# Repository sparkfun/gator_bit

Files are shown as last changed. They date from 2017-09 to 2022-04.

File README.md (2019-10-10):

SparkFun gator:bit v2
========================================

SparkFun gator:bit v2

[*SparkFun gator:bit v2 (15162)*](https://www.sparkfun.com/products/15162)

The SparkFun gator:bit is an all-in-one prototyping platform for the micro:bit. Each pin is accessible by alligator clip, eliminating the need for breadboard or jumper wires.

Repository Contents
------------------
* **/Firmware** - Example code used with gator:bit. While they are compiled HEX codes, you can modify the example code once they are imported into MakeCode editor.
* **/Hardware** - Eagle design files (.brd, .sch)
* **/Production** - Production panel files (.brd)

Documentation
--------------
* **[Hookup Guide](https://learn.sparkfun.com/tutorials/sparkfun-gatorbit-v20-hookup-guide)** - Basic hookup guide for the gator:bit v2.

Versions
--------------
* **[v1](https://github.com/sparkfun/gator_bit/tree/v10)** - Version 1, Initial Release
* **[v2](https://github.com/sparkfun/gator_bit/)** - Version 2, Updated power handling, output pins now reach a proper voltage.

License Information
-------------------

This product is _**open source**_! 

Please review the LICENSE.md file for license information. 

If you have any questions or concerns on licensing, please contact techsupport@sparkfun.com.

Distributed as-is; no warranty is given.

- Your friends at SparkFun.

_<COLLABORATION CREDIT>_

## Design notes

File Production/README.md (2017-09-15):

SparkFun <PRODUCT NAME> Production Files
=========================================

These are the production files SparkFun uses for printing PCBs.

License Information
-------------------
This product is open source! 

The hardware is released under [Creative Commons ShareAlike 4.0 International](https://creativecommons.org/licenses/by-sa/4.0/).

Please use, reuse, and modify these files as you see fit. Please maintain attribution to SparkFun Electronics and release anything derivative under the same license.

Distributed as-is; no warranty is given.

- Your friends at SparkFun.

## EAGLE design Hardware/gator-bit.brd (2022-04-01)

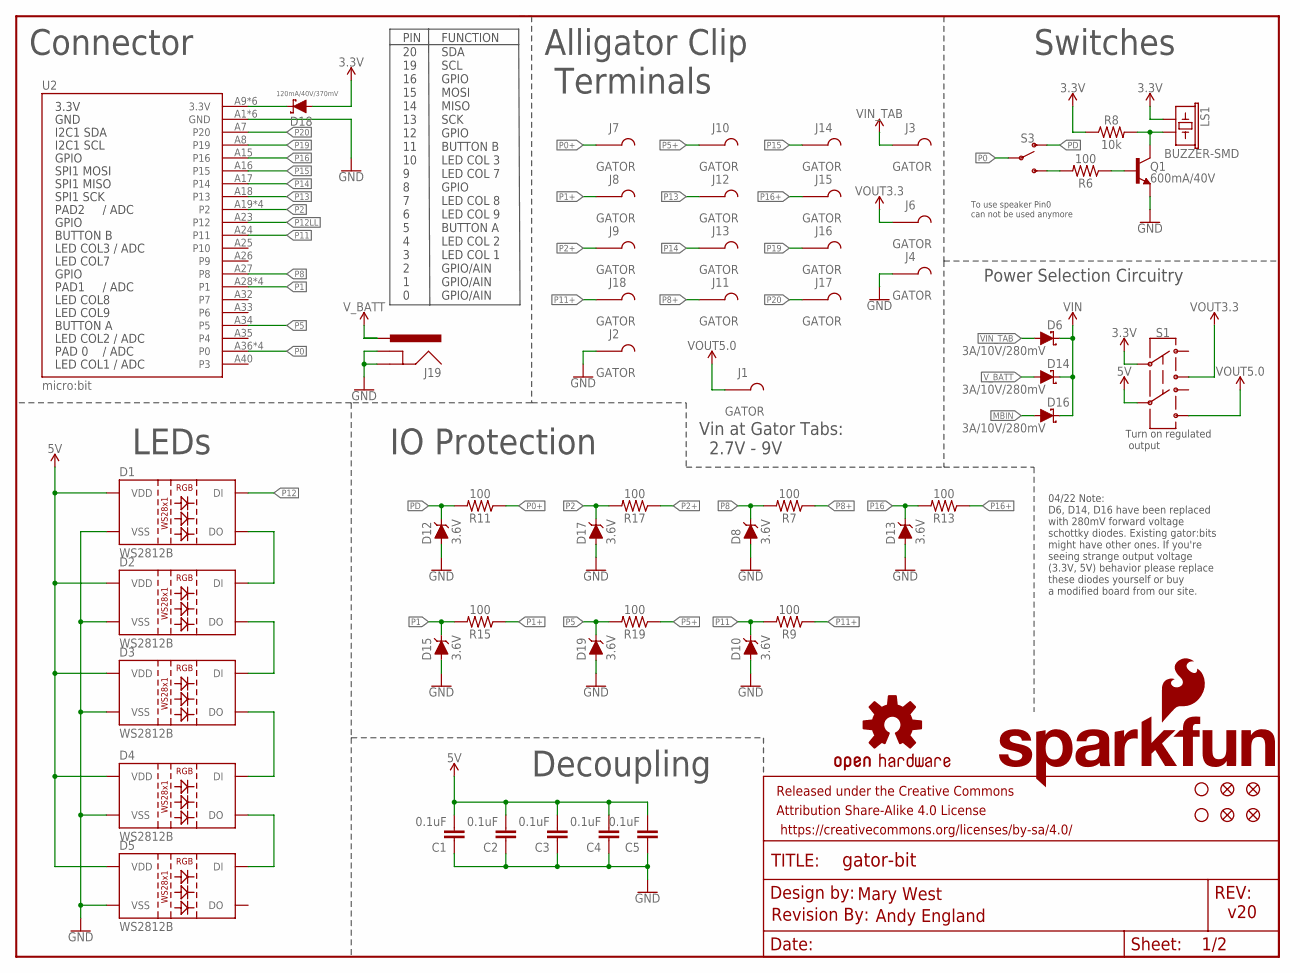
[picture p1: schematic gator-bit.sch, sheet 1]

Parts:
C1, C2, C3, C4, C5: 0.1uF; 0603
D1, D2, D3, D4, D5: WS2812B
D6, D14, D16: 3A/10V/280mV; SOD-323
D8, D10, D12, D13, D15, D17, D19: 3.6V; SOD-323
D18: 120mA/40V/370mV; SOD-523
FD1, FD2, FD3, FD4: FIDUCIAL1X2; FIDUCIAL-1X2
FRAME1: FRAME-LETTER; CREATIVE_COMMONS
H1, H2: STAND-OFF
J1, J2, J3, J4, J6, J7, J8, J9, J10, J11, J12, J13, J14, J15, J16, J17, J18: GATOR
J19: POWER_JACKPTH_LOCK; POWER_JACK_PTH_LOCK
LOGO1: SFE_LOGO_NAME_FLAME.3_INCH; SFE_LOGO_NAME_FLAME_.3
LOGO2: OSHW-LOGOM; OSHW-LOGO-M
LOGO3: REVISION
LS1: BUZZER-SMD; BUZZER-CCV
Q1: 600mA/40V; SOT23-3
R6, R7, R9, R11, R13, R15, R17, R19: 100; 0603
R8: 10k; 0603
S1: SWITCH-DPDT-SMD-AYZ0202; SWITCH_DPDT_SMD_AYZ0202
S3: SWITCH-SPDT-SMD-AYZ0202; SWITCH_DPDT_SMD_AYZ0202
U2: micro:bit; MICRO:BIT_RA_PTH

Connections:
3.3V: D18.A, LS1.+ (1), R8.1, S1.2; also elsewhere on the board
5V: C1.2, C2.2, C3.2, C4.2, C5.2, D1.1 (VDD), D2.1 (VDD), D3.1 (VDD), D4.1 (VDD), D5.1 (VDD), S1.5; also elsewhere on the board
GND: C1.1, C2.1, C3.1, C4.1, C5.1, D1.3 (VSS), D2.3 (VSS), D3.3 (VSS), D4.3 (VSS), D5.3 (VSS), D8.A, D10.A, D12.A, D13.A, D15.A, D17.A, D19.A, J2.P$1, J2.P$2, J4.P$1, J4.P$2, J19.GND, J19.GNDBREAK, Q1.2 (E), U2.A1 (GND), U2.A2 (GND), U2.A3 (GND), U2.A4 (GND), U2.A5 (GND), U2.A6 (GND); also elsewhere on the board
MBIN: D16.A, D18.C, U2.A9 (3.3V), U2.A10 (3.3V), U2.A11 (3.3V), U2.A12 (3.3V), U2.A13 (3.3V), U2.A14 (3.3V)
unnamed: LS1.- (2), Q1.3 (C), R8.2
unnamed: D1.2 (DO), D2.4 (DI)
unnamed: D2.2 (DO), D3.4 (DI)
unnamed: D3.2 (DO), D4.4 (DI)
unnamed: D4.2 (DO), D5.4 (DI)
unnamed: R6.2, S3.3 (S)
unnamed: Q1.1 (B), R6.1
P0: S3.2, U2.A36 (P0), U2.A37 (P0), U2.A38 (P0), U2.A39 (P0)
P0+: J7.P$1, J7.P$2, R11.1
P1: D15.C, R15.2, U2.A28 (P1), U2.A29 (P1), U2.A30 (P1), U2.A31 (P1)
P1+: J8.P$1, J8.P$2, R15.1
P2: D17.C, R17.2, U2.A19 (P2), U2.A20 (P2), U2.A21 (P2), U2.A22 (P2)
P2+: J9.P$1, J9.P$2, R17.1
P5: D19.C, R19.2, U2.A34 (P5)
P5+: J10.P$1, J10.P$2, R19.1
P8: D8.C, R7.2, U2.A27 (P8)
P8+: J11.P$1, J11.P$2, R7.1
P11: D10.C, R9.2, U2.A24 (P11)
P11+: J18.P$1, J18.P$2, R9.1
P12: D1.4 (DI); also elsewhere on the board
P12LL: U2.A23 (P12); also elsewhere on the board
P13: J12.P$1, J12.P$2, U2.A18 (P13)
P14: J13.P$1, J13.P$2, U2.A17 (P14)
P15: J14.P$1, J14.P$2, U2.A16 (P15)
P16: D13.C, R13.2, U2.A15 (P16)
P16+: J15.P$1, J15.P$2, R13.1
P19: J16.P$1, J16.P$2, U2.A8 (P19)
P20: J17.P$1, J17.P$2, U2.A7 (P20)
PD: D12.C, R11.2, S3.1 (O)
VIN: D6.C, D14.C, D16.C; also elsewhere on the board
VIN_TAB: D6.A, J3.P$1, J3.P$2
VOUT3.3: J6.P$1, J6.P$2, S1.3; also elsewhere on the board
VOUT5.0: J1.P$1, J1.P$2, S1.6; also elsewhere on the board
V_BATT: D14.A, J19.PWR

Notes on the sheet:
v20
Connector
20 19 16 15 14 13 12 11 10 9 8 7 6 5 4 3 2 1 0
SDA SCL GPIO MOSI MISO SCK GPIO BUTTON B LED COL 3 LED COL 7 GPIO LED COL 8 LED COL 9 BUTTON A LED COL 2 LED COL 1 GPIO/AIN GPIO/AIN GPIO/AIN
PIN
FUNCTION
Mary West
Alligator Clip Terminals
Switches
LEDs
Decoupling
IO Protection
To use speaker Pin0 can not be used anymore
Power Selection Circuitry
Turn on regulated output
Vin at Gator Tabs: 2.7V - 9V
Andy England
04/22 Note: D6, D14, D16 have been replaced with 280mV forward voltage schottky diodes. Existing gator:bits might have other ones. If you're seeing strange output voltage (3.3V, 5V) behavior please replace these diodes yourself or buy a modified board from our site.

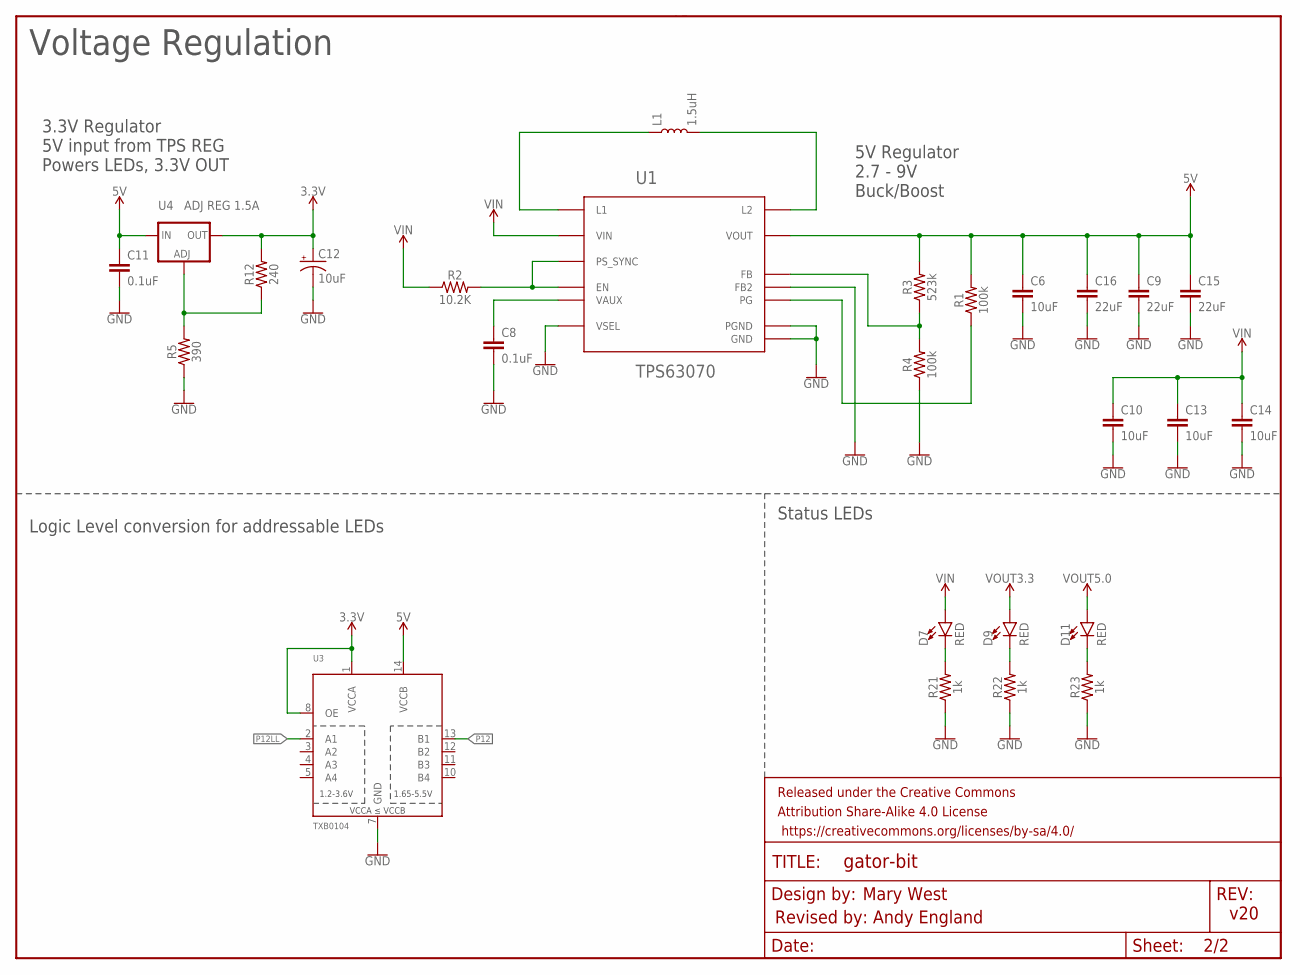
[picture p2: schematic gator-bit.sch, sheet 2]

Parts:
C6, C14: 10uF; 0603
C8, C11: 0.1uF; 0603
C9, C15, C16: 22uF; 0805
C10, C13: 10uF; 0805
C12: 10uF; EIA3216
D7, D9, D11: RED; LED-0603
FRAME3: FRAME-LETTER; CREATIVE_COMMONS
L1: 1.5uH; XFL4020
R1, R4: 100k; 0603
R2: 10.2K; 0603
R3: 523k; 0603
R5: 390; 0603
R12: 240; 0603
R21, R22, R23: 1k; 0603
U1: TPS63070; TPS63070RNM
U3: TXB0104; TSSOP14
U4: ADJ REG 1.5A; SOT223

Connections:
3.3V: C12.+, R12.2, U3.1 (VCCA), U3.8 (OE), U4.2 (OUT), U4.4 (OUT); also elsewhere on the board
5V: C6.1, C9.1, C11.1, C15.1, C16.1, R1.2, R3.2, U1.P$7 (VOUT), U3.14 (VCCB), U4.3 (IN); also elsewhere on the board
GND: C6.2, C8.2, C9.2, C10.2, C11.2, C12.-, C13.2, C14.2, C15.2, C16.2, R4.1, R5.1, R21.1, R22.1, R23.1, U1.P$4 (GND), U1.P$6 (FB2), U1.P$10 (PGND), U1.P$15 (VSEL), U3.7 (GND); also elsewhere on the board
unnamed: L1.P$1 (1), U1.P$11 (L1)
unnamed: L1.P$2 (2), U1.P$9 (L2)
unnamed: D7.C, R21.2
unnamed: R3.1, R4.2, U1.P$5 (FB)
unnamed: C8.1, U1.P$3 (VAUX)
unnamed: R2.2, U1.P$1 (PS_SYNC), U1.P$14 (EN)
unnamed: R1.1, U1.P$2 (PG)
unnamed: R5.2, R12.1, U4.1 (ADJ)
unnamed: D9.C, R22.2
unnamed: D11.C, R23.2
P12: U3.13 (B1); also elsewhere on the board
P12LL: U3.2 (A1); also elsewhere on the board
VIN: C10.1, C13.1, C14.1, D7.A, R2.1, U1.P$12 (VIN); also elsewhere on the board
VOUT3.3: D9.A; also elsewhere on the board
VOUT5.0: D11.A; also elsewhere on the board

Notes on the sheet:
Voltage Regulation
Mary West
v20
5V Regulator 2.7 - 9V Buck/Boost
3.3V Regulator 5V input from TPS REG Powers LEDs, 3.3V OUT
Logic Level conversion for addressable LEDs
Status LEDs
Revised by: Andy England

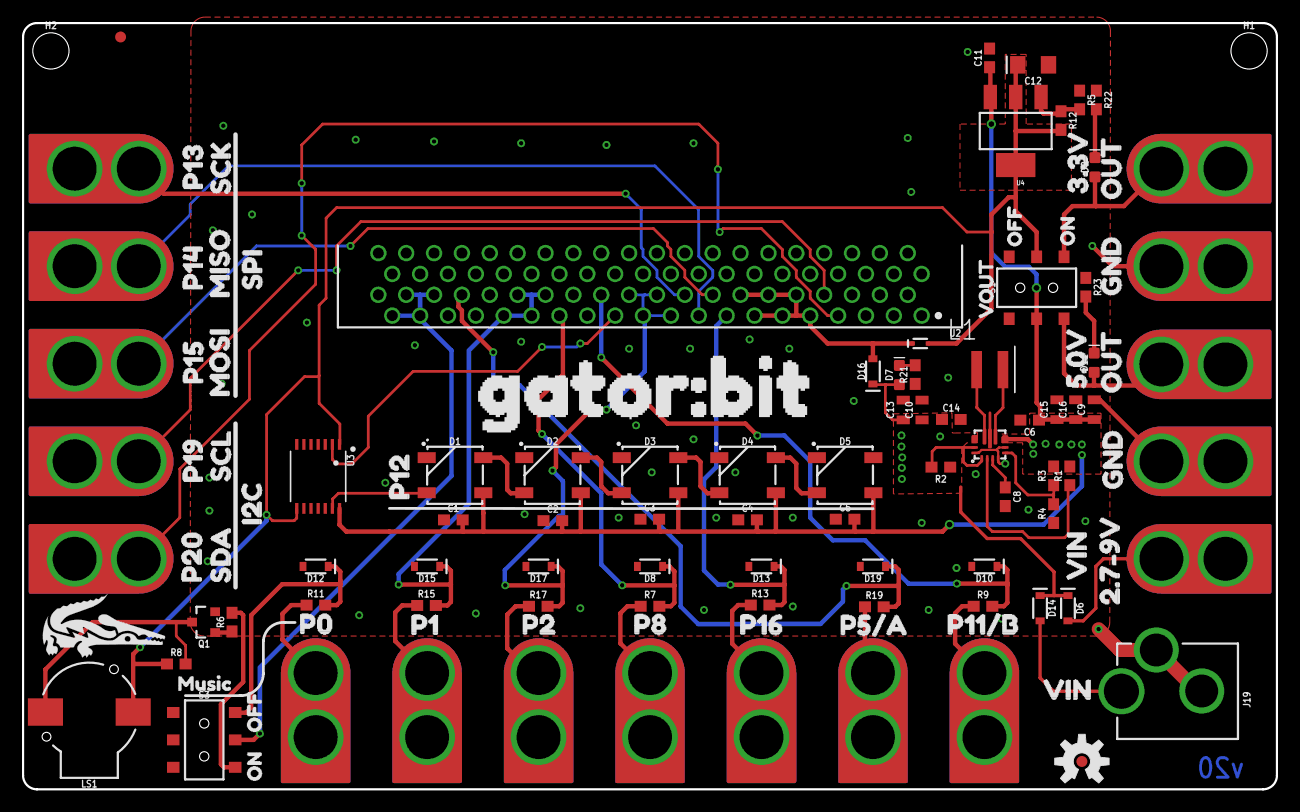
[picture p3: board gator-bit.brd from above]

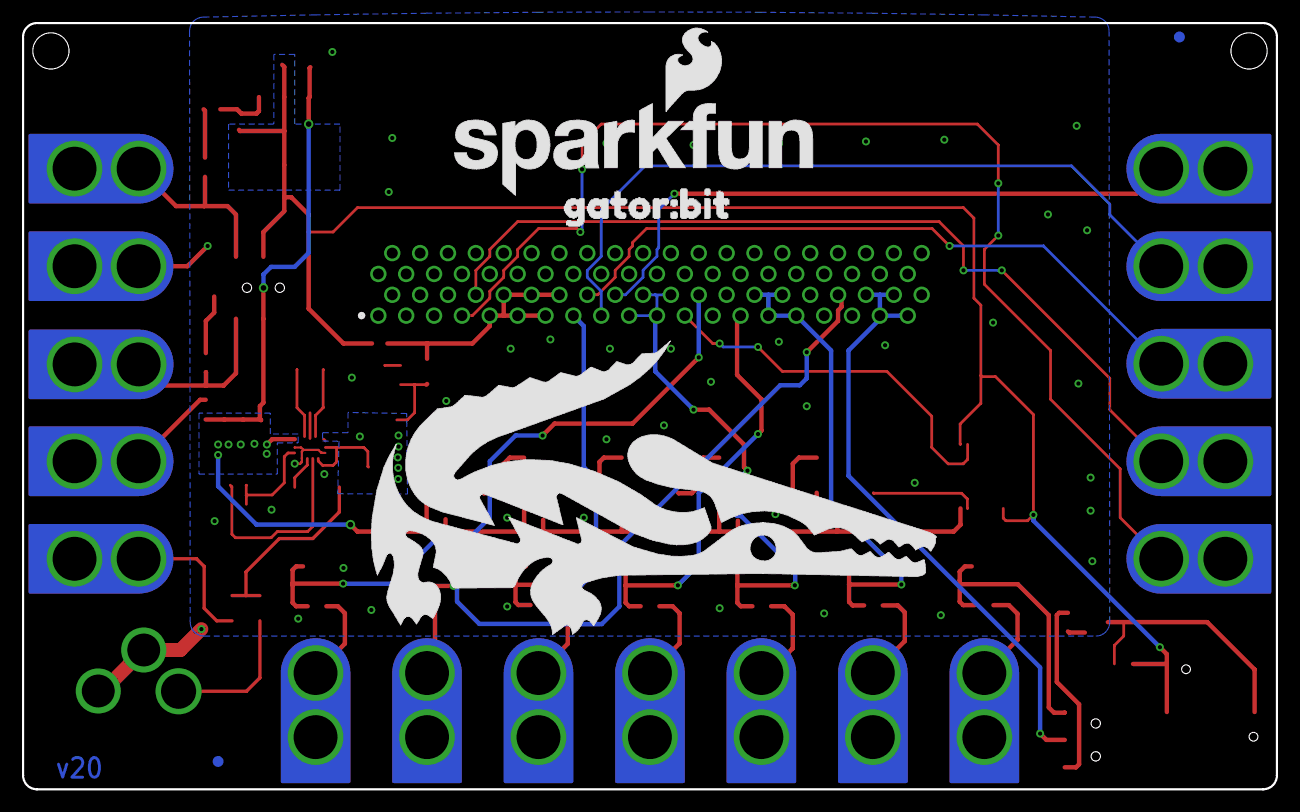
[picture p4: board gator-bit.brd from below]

Board: 2 copper layers, 114.3 x 69.8 mm, 128 parts (4 on the bottom side), 48 nets.

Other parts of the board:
U$1: 2#7#9V21
U$2: 3#3V25
U$3: 5#0V23
U$4: ORDERING_INSTRUCTIONS
U$5: GATOR#BIT26
U$6: GATOR#BIT32
U$7, U$8: GND22
U$9: I2C7
U$10: MISO5
U$11: MOSI4
U$12: MUSIC28
U$13, U$36: OFF29
U$14, U$37: ON30
U$15, U$16: OUT24
U$17: P5#A18
U$18: P11#B19
U$19: P013
U$20: P114
U$21: P130
U$22: P199
U$23: P208
U$24: P215
U$25: P816
U$26: P1227
U$27: P1411
U$28: P1510
U$29: P1617
U$30: SCK1
U$31: SCL2
U$32: SDA3
U$33: SPI6
U$34, U$39: VIN20
U$35: VOUT31

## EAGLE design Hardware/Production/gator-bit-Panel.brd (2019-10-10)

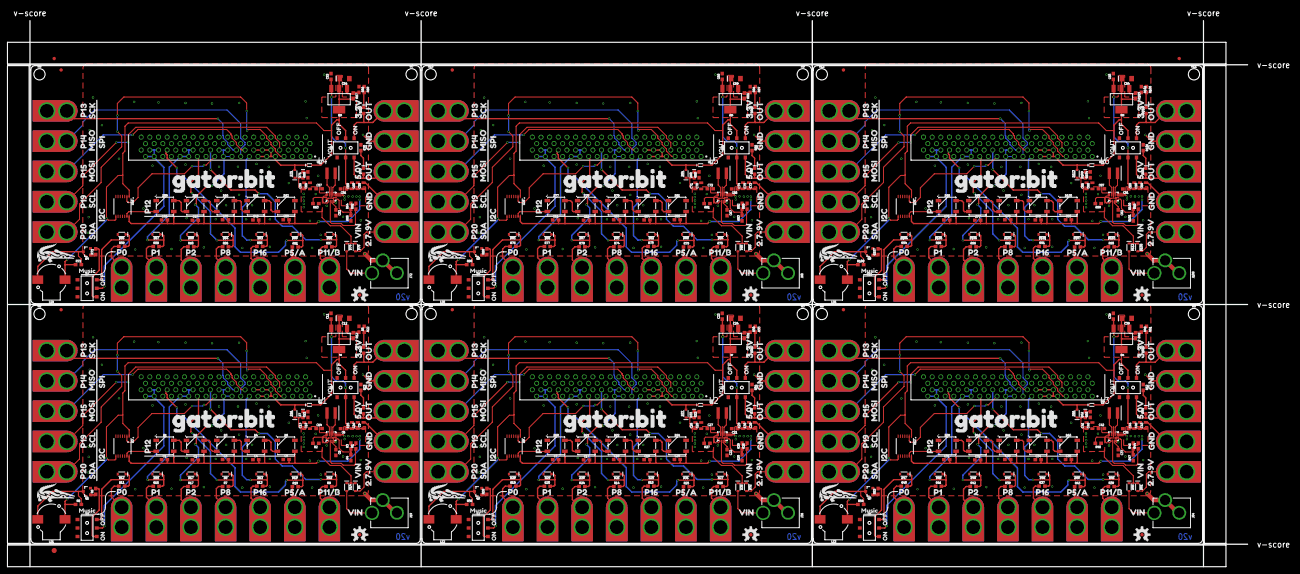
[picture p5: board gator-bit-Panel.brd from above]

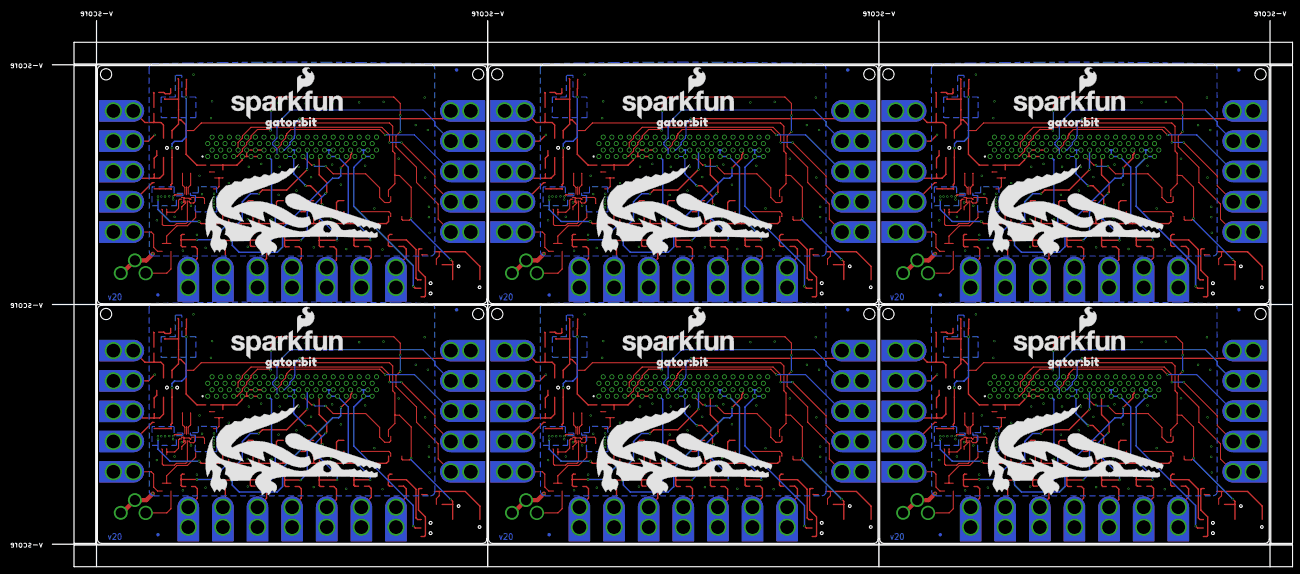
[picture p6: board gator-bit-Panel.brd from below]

Board: 2 copper layers, 364.0 x 160.3 mm, 765 parts (24 on the bottom side), 288 nets.

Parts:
C1, C2, C3, C4, C5, C7, C8, C11, C17, C18, C19, C20, C22, C23, C31, C32, C33, C34, C35, C37, C38, C46, C47, C48, C49, C50, C52, C53, C61, C62, C63, C64, C65, C67, C68, C76, C77, C78, C79, C80, C82, C83: 0.1uF; 0603
C6, C14, C21, C27, C36, C42, C51, C57, C66, C72, C81, C87: 10uF; 0603
C9, C15, C16, C28, C29, C30, C43, C44, C45, C58, C59, C60, C73, C74, C75, C88, C89, C90: 22uF; 0805
C10, C13, C25, C26, C40, C41, C55, C56, C70, C71, C85, C86: 10uF; 0805
C12, C24, C39, C54, C69, C84: 10uF; EIA3216
D1, D2, D3, D4, D5, D20, D21, D22, D23, D24, D39, D40, D41, D42, D43, D58, D59, D60, D61, D62, D77, D78, D79, D80, D81, D96, D97, D98, D99, D100: WS2812B
D6, D14, D16, D32, D36, D37, D51, D55, D56, D70, D74, D75, D89, D93, D94, D108, D112, D113: 1A/23V/620mV; SOD-323
D7, D9, D11, D33, D34, D35, D52, D53, D54, D71, D72, D73, D90, D91, D92, D109, D110, D111: RED; LED-0603
D8, D10, D12, D13, D15, D17, D19, D25, D26, D27, D28, D29, D30, D31, D44, D45, D46, D47, D48, D49, D50, D63, D64, D65, D66, D67, D68, D69, D82, D83, D84, D85, D86, D87, D88, D101, D102, D103, D104, D105, D106, D107: 3.6V; SOD-323
D18, D38, D57, D76, D95, D114: 120mA/40V/370mV; SOD-523
E$1, E$2: FIDUCIAL-1X2
E$3: FIDUCIAL-1.5X3
FD1, FD2, FD3, FD4, FD5, FD6, FD7, FD8, FD9, FD10, FD11, FD12, FD13, FD14, FD15, FD16, FD17, FD18, FD19, FD20, FD21, FD22, FD23, FD24: FIDUCIAL1X2; FIDUCIAL-1X2
FRAME1, FRAME2, FRAME3, FRAME4, FRAME5, FRAME6, FRAME7, FRAME8, FRAME9, FRAME10, FRAME11, FRAME12: FRAME-LETTER; CREATIVE_COMMONS
H1, H2, H3, H4, H5, H6, H7, H8, H9, H10, H11, H12: STAND-OFF
J1, J2, J3, J4, J5, J6, J7, J8, J9, J10, J11, J12, J13, J14, J15, J16, J17, J18, J20, J21, J22, J23, J24, J25, J26, J27, J28, J29, J30, J31, J32, J33, J34, J35, J37, J38, J39, J40, J41, J42, J43, J44, J45, J46, J47, J48, J49, J50, J51, J52, J53, J55, J56, J57, J58, J59, J60, J61, J62, J63, J64, J65, J66, J67, J68, J69, J70, J71, J73, J74, J75, J76, J77, J78, J79, J80, J81, J82, J83, J84, J85, J86, J87, J88, J89, J91, J92, J93, J94, J95, J96, J97, J98, J99, J100, J101, J102, J103, J104, J105, J106, J107: GATOR
J19, J36, J54, J72, J90, J108: POWER_JACKPTH_LOCK; POWER_JACK_PTH_LOCK
L1, L2, L3, L4, L5, L6: 1.5uH; XFL4020
LOGO1, LOGO4, LOGO7, LOGO10, LOGO13, LOGO16: SFE_LOGO_NAME_FLAME.3_INCH; SFE_LOGO_NAME_FLAME_.3
LOGO2, LOGO5, LOGO8, LOGO11, LOGO14, LOGO17: OSHW-LOGOM; OSHW-LOGO-M
LOGO3, LOGO6, LOGO9, LOGO12, LOGO15, LOGO18: REVISION
LS1, LS2, LS3, LS4, LS5, LS6: BUZZER-SMD; BUZZER-CCV
Q1, Q2, Q3, Q4, Q5, Q6: 600mA/40V; SOT23-3
R1, R4, R26, R29, R44, R47, R62, R65, R80, R83, R98, R101: 100k; 0603
R2, R27, R45, R63, R81, R99: 10.2K; 0603
R3, R28, R46, R64, R82, R100: 523k; 0603
R5, R30, R48, R66, R84, R102: 390; 0603
R6, R7, R9, R10, R11, R13, R14, R15, R16, R17, R18, R19, R20, R24, R25, R35, R37, R38, R39, R40, R41, R42, R43, R53, R55, R56, R57, R58, R59, R60, R61, R71, R73, R74, R75, R76, R77, R78, R79, R89, R91, R92, R93, R94, R95, R96, R97, R107: 100; 0603
R8, R36, R54, R72, R90, R108: 10k; 0603
R12, R31, R49, R67, R85, R103: 240; 0603
R21, R22, R23, R32, R33, R34, R50, R51, R52, R68, R69, R70, R86, R87, R88, R104, R105, R106: 1k; 0603
S1, S2, S3, S4, S5, S6, S7, S8, S9, S10, S11, S12: SWITCH_DPDT_SMD_AYZ0202
U1, U6, U10, U14, U18, U22: TPS63070; TPS63070RNM
U2, U5, U9, U13, U17, U21: micro:bit; MICRO:BIT_RA_PTH
U3, U8, U12, U16, U20, U24: TXB0104; TSSOP14
U4, U7, U11, U15, U19, U23: ADJ REG 1.5A; SOT223
U$1, U$4, U$75, U$112, U$149, U$186: 2#7#9V21
U$2, U$38, U$76, U$113, U$150, U$187: 3#3V25
U$3, U$40, U$77, U$114, U$151, U$188: 5#0V23
U$5, U$41, U$78, U$115, U$152, U$189: GATOR#BIT26
U$6, U$42, U$79, U$116, U$153, U$190: GATOR#BIT32
U$7, U$8, U$43, U$44, U$80, U$81, U$117, U$118, U$154, U$155, U$191, U$192: GND22
U$9, U$45, U$82, U$119, U$156, U$193: I2C7
U$10, U$46, U$83, U$120, U$157, U$194: MISO5
U$11, U$47, U$84, U$121, U$158, U$195: MOSI4
U$12, U$48, U$85, U$122, U$159, U$196: MUSIC28
U$13, U$36, U$49, U$72, U$86, U$109, U$123, U$146, U$160, U$183, U$197, U$220: OFF29
U$14, U$37, U$50, U$73, U$87, U$110, U$124, U$147, U$161, U$184, U$198, U$221: ON30
U$15, U$16, U$51, U$52, U$88, U$89, U$125, U$126, U$162, U$163, U$199, U$200: OUT24
U$17, U$53, U$90, U$127, U$164, U$201: P5#A18
U$18, U$54, U$91, U$128, U$165, U$202: P11#B19
U$19, U$55, U$92, U$129, U$166, U$203: P013
U$20, U$56, U$93, U$130, U$167, U$204: P114
U$21, U$57, U$94, U$131, U$168, U$205: P130
U$22, U$58, U$95, U$132, U$169, U$206: P199
U$23, U$59, U$96, U$133, U$170, U$207: P208
U$24, U$60, U$97, U$134, U$171, U$208: P215
U$25, U$61, U$98, U$135, U$172, U$209: P816
U$26, U$62, U$99, U$136, U$173, U$210: P1227
U$27, U$63, U$100, U$137, U$174, U$211: P1411
U$28, U$64, U$101, U$138, U$175, U$212: P1510
U$29, U$65, U$102, U$139, U$176, U$213: P1617
U$30, U$66, U$103, U$140, U$177, U$214: SCK1
U$31, U$67, U$104, U$141, U$178, U$215: SCL2
U$32, U$68, U$105, U$142, U$179, U$216: SDA3
U$33, U$69, U$106, U$143, U$180, U$217: SPI6
U$34, U$39, U$70, U$74, U$107, U$111, U$144, U$148, U$181, U$185, U$218, U$222: VIN20
U$35, U$71, U$108, U$145, U$182, U$219: VOUT31

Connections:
3.3V: C12.+, D18.A, LS1.+, R8.1, R12.2, S1.2, U3.1, U3.8, U4.2, U4.4
3.3V1: C24.+, D38.A, LS2.+, R31.2, R36.1, S4.2, U7.2, U7.4, U8.1, U8.8
3.3V2: C39.+, D57.A, LS3.+, R49.2, R54.1, S6.2, U11.2, U11.4, U12.1, U12.8
3.3V3: C54.+, D76.A, LS4.+, R67.2, R72.1, S8.2, U15.2, U15.4, U16.1, U16.8
3.3V4: C69.+, D95.A, LS5.+, R85.2, R90.1, S10.2, U19.2, U19.4, U20.1, U20.8
3.3V5: C84.+, D114.A, LS6.+, R103.2, R108.1, S12.2, U23.2, U23.4, U24.1, U24.8
5V: C1.2, C2.2, C3.2, C4.2, C5.2, C6.1, C9.1, C11.1, C15.1, C16.1, D1.1, D2.1, D3.1, D4.1, D5.1, R1.2, R3.2, S1.5, U1.P$7, U3.14, U4.3
5V1: C7.2, C17.2, C18.2, C19.2, C20.2, C21.1, C23.1, C28.1, C29.1, C30.1, D20.1, D21.1, D22.1, D23.1, D24.1, R26.2, R28.2, S4.5, U6.P$7, U7.3, U8.14
5V2: C31.2, C32.2, C33.2, C34.2, C35.2, C36.1, C38.1, C43.1, C44.1, C45.1, D39.1, D40.1, D41.1, D42.1, D43.1, R44.2, R46.2, S6.5, U10.P$7, U11.3, U12.14
5V3: C46.2, C47.2, C48.2, C49.2, C50.2, C51.1, C53.1, C58.1, C59.1, C60.1, D58.1, D59.1, D60.1, D61.1, D62.1, R62.2, R64.2, S8.5, U14.P$7, U15.3, U16.14
5V4: C61.2, C62.2, C63.2, C64.2, C65.2, C66.1, C68.1, C73.1, C74.1, C75.1, D77.1, D78.1, D79.1, D80.1, D81.1, R80.2, R82.2, S10.5, U18.P$7, U19.3, U20.14
5V5: C76.2, C77.2, C78.2, C79.2, C80.2, C81.1, C83.1, C88.1, C89.1, C90.1, D96.1, D97.1, D98.1, D99.1, D100.1, R98.2, R100.2, S12.5, U22.P$7, U23.3, U24.14
GND: C1.1, C2.1, C3.1, C4.1, C5.1, C6.2, C8.2, C9.2, C10.2, C11.2, C12.-, C13.2, C14.2, C15.2, C16.2, D1.3, D2.3, D3.3, D4.3, D5.3, D8.A, D10.A, D12.A, D13.A, D15.A, D17.A, D19.A, J2.P$1, J2.P$2, J4.P$1, J4.P$2, J19.GND, J19.GNDBREAK, Q1.2, R4.1, R5.1, R21.1, R22.1, R23.1, U1.P$4, U1.P$6, U1.P$10, U1.P$15, U2.A1, U2.A2, U2.A3, U2.A4, U2.A5, U2.A6, U3.7
GND1: C7.1, C17.1, C18.1, C19.1, C20.1, C21.2, C22.2, C23.2, C24.-, C25.2, C26.2, C27.2, C28.2, C29.2, C30.2, D20.3, D21.3, D22.3, D23.3, D24.3, D25.A, D26.A, D27.A, D28.A, D29.A, D30.A, D31.A, J32.P$1, J32.P$2, J34.P$1, J34.P$2, J36.GND, J36.GNDBREAK, Q2.2, R29.1, R30.1, R32.1, R33.1, R34.1, U5.A1, U5.A2, U5.A3, U5.A4, U5.A5, U5.A6, U6.P$4, U6.P$6, U6.P$10, U6.P$15, U8.7
GND2: C31.1, C32.1, C33.1, C34.1, C35.1, C36.2, C37.2, C38.2, C39.-, C40.2, C41.2, C42.2, C43.2, C44.2, C45.2, D39.3, D40.3, D41.3, D42.3, D43.3, D44.A, D45.A, D46.A, D47.A, D48.A, D49.A, D50.A, J50.P$1, J50.P$2, J52.P$1, J52.P$2, J54.GND, J54.GNDBREAK, Q3.2, R47.1, R48.1, R50.1, R51.1, R52.1, U9.A1, U9.A2, U9.A3, U9.A4, U9.A5, U9.A6, U10.P$4, U10.P$6, U10.P$10, U10.P$15, U12.7
GND3: C46.1, C47.1, C48.1, C49.1, C50.1, C51.2, C52.2, C53.2, C54.-, C55.2, C56.2, C57.2, C58.2, C59.2, C60.2, D58.3, D59.3, D60.3, D61.3, D62.3, D63.A, D64.A, D65.A, D66.A, D67.A, D68.A, D69.A, J68.P$1, J68.P$2, J70.P$1, J70.P$2, J72.GND, J72.GNDBREAK, Q4.2, R65.1, R66.1, R68.1, R69.1, R70.1, U13.A1, U13.A2, U13.A3, U13.A4, U13.A5, U13.A6, U14.P$4, U14.P$6, U14.P$10, U14.P$15, U16.7
GND4: C61.1, C62.1, C63.1, C64.1, C65.1, C66.2, C67.2, C68.2, C69.-, C70.2, C71.2, C72.2, C73.2, C74.2, C75.2, D77.3, D78.3, D79.3, D80.3, D81.3, D82.A, D83.A, D84.A, D85.A, D86.A, D87.A, D88.A, J86.P$1, J86.P$2, J88.P$1, J88.P$2, J90.GND, J90.GNDBREAK, Q5.2, R83.1, R84.1, R86.1, R87.1, R88.1, U17.A1, U17.A2, U17.A3, U17.A4, U17.A5, U17.A6, U18.P$4, U18.P$6, U18.P$10, U18.P$15, U20.7
GND5: C76.1, C77.1, C78.1, C79.1, C80.1, C81.2, C82.2, C83.2, C84.-, C85.2, C86.2, C87.2, C88.2, C89.2, C90.2, D96.3, D97.3, D98.3, D99.3, D100.3, D101.A, D102.A, D103.A, D104.A, D105.A, D106.A, D107.A, J104.P$1, J104.P$2, J106.P$1, J106.P$2, J108.GND, J108.GNDBREAK, Q6.2, R101.1, R102.1, R104.1, R105.1, R106.1, U21.A1, U21.A2, U21.A3, U21.A4, U21.A5, U21.A6, U22.P$4, U22.P$6, U22.P$10, U22.P$15, U24.7
MBIN: D16.A, D18.C, U2.A9, U2.A10, U2.A11, U2.A12, U2.A13, U2.A14
MBIN1: D37.A, D38.C, U5.A9, U5.A10, U5.A11, U5.A12, U5.A13, U5.A14
MBIN2: D56.A, D57.C, U9.A9, U9.A10, U9.A11, U9.A12, U9.A13, U9.A14
MBIN3: D75.A, D76.C, U13.A9, U13.A10, U13.A11, U13.A12, U13.A13, U13.A14
MBIN4: D94.A, D95.C, U17.A9, U17.A10, U17.A11, U17.A12, U17.A13, U17.A14
MBIN5: D113.A, D114.C, U21.A9, U21.A10, U21.A11, U21.A12, U21.A13, U21.A14
unnamed: D20.2, D21.4
unnamed: L1.P$1, U1.P$11
unnamed: LS1.-, Q1.3, R8.2
unnamed: D1.2, D2.4
unnamed: D2.2, D3.4
unnamed: D3.2, D4.4
unnamed: D4.2, D5.4
unnamed: L1.P$2, U1.P$9
unnamed: D7.C, R21.2
unnamed: D21.2, D22.4
unnamed: R3.1, R4.2, U1.P$5
unnamed: C8.1, U1.P$3
unnamed: R2.2, U1.P$1, U1.P$14
unnamed: R1.1, U1.P$2
unnamed: D22.2, D23.4
unnamed: R5.2, R12.1, U4.1
unnamed: D23.2, D24.4
unnamed: L2.P$1, U6.P$11
unnamed: L2.P$2, U6.P$9
unnamed: R6.2, S3.3
unnamed: R27.2, U6.P$1, U6.P$14
unnamed: D9.C, R22.2
unnamed: D11.C, R23.2
unnamed: Q1.1, R6.1
unnamed: C22.1, U6.P$3
unnamed: R28.1, R29.2, U6.P$5
unnamed: R26.1, U6.P$2
unnamed: R30.2, R31.1, U7.1
unnamed: D33.C, R32.2
unnamed: D34.C, R33.2
unnamed: D35.C, R34.2
unnamed: R35.2, S2.3
unnamed: Q2.1, R35.1
unnamed: LS2.-, Q2.3, R36.2
unnamed: D39.2, D40.4
unnamed: D40.2, D41.4
unnamed: D41.2, D42.4
unnamed: D42.2, D43.4
unnamed: L3.P$1, U10.P$11
unnamed: L3.P$2, U10.P$9
unnamed: R45.2, U10.P$1, U10.P$14
unnamed: C37.1, U10.P$3
unnamed: R46.1, R47.2, U10.P$5
unnamed: R44.1, U10.P$2
unnamed: R48.2, R49.1, U11.1
unnamed: D52.C, R50.2
unnamed: D53.C, R51.2
unnamed: D54.C, R52.2
unnamed: R53.2, S5.3
unnamed: Q3.1, R53.1
unnamed: LS3.-, Q3.3, R54.2
unnamed: D58.2, D59.4
unnamed: D59.2, D60.4
unnamed: D60.2, D61.4
unnamed: D61.2, D62.4
unnamed: L4.P$1, U14.P$11
unnamed: L4.P$2, U14.P$9
unnamed: R63.2, U14.P$1, U14.P$14
unnamed: C52.1, U14.P$3
unnamed: R64.1, R65.2, U14.P$5
unnamed: R62.1, U14.P$2
unnamed: R66.2, R67.1, U15.1
unnamed: D71.C, R68.2
unnamed: D72.C, R69.2
unnamed: D73.C, R70.2
unnamed: R71.2, S7.3
unnamed: Q4.1, R71.1
unnamed: LS4.-, Q4.3, R72.2
unnamed: D77.2, D78.4
unnamed: D78.2, D79.4
unnamed: D79.2, D80.4
unnamed: D80.2, D81.4
unnamed: L5.P$1, U18.P$11
unnamed: L5.P$2, U18.P$9
unnamed: R81.2, U18.P$1, U18.P$14
unnamed: C67.1, U18.P$3
unnamed: R82.1, R83.2, U18.P$5
unnamed: R80.1, U18.P$2
unnamed: R84.2, R85.1, U19.1
unnamed: D90.C, R86.2
unnamed: D91.C, R87.2
unnamed: D92.C, R88.2
unnamed: R89.2, S9.3
unnamed: Q5.1, R89.1
unnamed: LS5.-, Q5.3, R90.2
unnamed: D96.2, D97.4
unnamed: D97.2, D98.4
unnamed: D98.2, D99.4
unnamed: D99.2, D100.4
unnamed: L6.P$1, U22.P$11
unnamed: L6.P$2, U22.P$9
unnamed: R99.2, U22.P$1, U22.P$14
unnamed: C82.1, U22.P$3
unnamed: R100.1, R101.2, U22.P$5
unnamed: R98.1, U22.P$2
unnamed: R102.2, R103.1, U23.1
unnamed: D109.C, R104.2
unnamed: D110.C, R105.2
unnamed: D111.C, R106.2
unnamed: R107.2, S11.3
unnamed: Q6.1, R107.1
unnamed: LS6.-, Q6.3, R108.2
P0: S3.2, U2.A36, U2.A37, U2.A38, U2.A39
P0+: J7.P$1, J7.P$2, R11.1
P0+1: J20.P$1, J20.P$2, R18.1
P0+2: J38.P$1, J38.P$2, R40.1
P0+3: J56.P$1, J56.P$2, R58.1
P0+4: J74.P$1, J74.P$2, R76.1
P0+5: J92.P$1, J92.P$2, R94.1
P1: D15.C, R15.2, U2.A28, U2.A29, U2.A30, U2.A31
P1+: J8.P$1, J8.P$2, R15.1
P1+1: J21.P$1, J21.P$2, R20.1
P1+2: J39.P$1, J39.P$2, R41.1
P1+3: J57.P$1, J57.P$2, R59.1
P1+4: J75.P$1, J75.P$2, R77.1
P1+5: J93.P$1, J93.P$2, R95.1
P2: D17.C, R17.2, U2.A19, U2.A20, U2.A21, U2.A22
P2+: J9.P$1, J9.P$2, R17.1
P2+1: J22.P$1, J22.P$2, R24.1
P2+2: J40.P$1, J40.P$2, R42.1
P2+3: J58.P$1, J58.P$2, R60.1
P2+4: J76.P$1, J76.P$2, R78.1
P2+5: J94.P$1, J94.P$2, R96.1
P3: D27.C, R16.2, U5.A24
P4: D31.C, R25.2, U5.A34
P5: D19.C, R19.2, U2.A34
P5+: J10.P$1, J10.P$2, R19.1
P5+1: J23.P$1, J23.P$2, R25.1
P5+2: J41.P$1, J41.P$2, R43.1
P5+3: J59.P$1, J59.P$2, R61.1
P5+4: J77.P$1, J77.P$2, R79.1
P5+5: J95.P$1, J95.P$2, R97.1
P6: S2.2, U5.A36, U5.A37, U5.A38, U5.A39
P7: D29.C, R20.2, U5.A28, U5.A29, U5.A30, U5.A31
P8: D8.C, R7.2, U2.A27
P8+: J11.P$1, J11.P$2, R7.1
P8+1: J24.P$1, J24.P$2, R14.1
P8+2: J42.P$1, J42.P$2, R38.1
P8+3: J60.P$1, J60.P$2, R56.1
P8+4: J78.P$1, J78.P$2, R74.1
P8+5: J96.P$1, J96.P$2, R92.1
P9: D26.C, R14.2, U5.A27
P10: D20.4, U8.13
P11: D10.C, R9.2, U2.A24
P11+: J18.P$1, J18.P$2, R9.1
P11+1: J31.P$1, J31.P$2, R16.1
P11+2: J49.P$1, J49.P$2, R39.1
P11+3: J67.P$1, J67.P$2, R57.1
P11+4: J85.P$1, J85.P$2, R75.1
P11+5: J103.P$1, J103.P$2, R93.1
P12: D1.4, U3.13
P12LL: U2.A23, U3.2
P12LL1: U5.A23, U8.2
P12LL2: U9.A23, U12.2
P12LL3: U13.A23, U16.2
P12LL4: U17.A23, U20.2
P12LL5: U21.A23, U24.2
P13: J12.P$1, J12.P$2, U2.A18
P14: J13.P$1, J13.P$2, U2.A17
P15: J14.P$1, J14.P$2, U2.A16
P16: D13.C, R13.2, U2.A15
P16+: J15.P$1, J15.P$2, R13.1
P16+1: J28.P$1, J28.P$2, R10.1
P16+2: J46.P$1, J46.P$2, R37.1
P16+3: J64.P$1, J64.P$2, R55.1
P16+4: J82.P$1, J82.P$2, R73.1
P16+5: J100.P$1, J100.P$2, R91.1
P17: D30.C, R24.2, U5.A19, U5.A20, U5.A21, U5.A22
P18: J25.P$1, J25.P$2, U5.A18
P19: J16.P$1, J16.P$2, U2.A8
P20: J17.P$1, J17.P$2, U2.A7
P21: J26.P$1, J26.P$2, U5.A17
P22: J27.P$1, J27.P$2, U5.A16
P23: D25.C, R10.2, U5.A15
P24: J29.P$1, J29.P$2, U5.A8
P25: J30.P$1, J30.P$2, U5.A7
P26: D46.C, R39.2, U9.A24
P27: D50.C, R43.2, U9.A34
P28: S5.2, U9.A36, U9.A37, U9.A38, U9.A39
P29: D48.C, R41.2, U9.A28, U9.A29, U9.A30, U9.A31
P30: D45.C, R38.2, U9.A27
P31: D39.4, U12.13
P32: D49.C, R42.2, U9.A19, U9.A20, U9.A21, U9.A22
P33: J43.P$1, J43.P$2, U9.A18
P34: J44.P$1, J44.P$2, U9.A17
P35: J45.P$1, J45.P$2, U9.A16
P36: D44.C, R37.2, U9.A15
P37: J47.P$1, J47.P$2, U9.A8
P38: J48.P$1, J48.P$2, U9.A7
P39: D65.C, R57.2, U13.A24
P40: D69.C, R61.2, U13.A34
P41: S7.2, U13.A36, U13.A37, U13.A38, U13.A39
P42: D67.C, R59.2, U13.A28, U13.A29, U13.A30, U13.A31
P43: D64.C, R56.2, U13.A27
P44: D58.4, U16.13
P45: D68.C, R60.2, U13.A19, U13.A20, U13.A21, U13.A22
P46: J61.P$1, J61.P$2, U13.A18
P47: J62.P$1, J62.P$2, U13.A17
P48: J63.P$1, J63.P$2, U13.A16
P49: D63.C, R55.2, U13.A15
P50: J65.P$1, J65.P$2, U13.A8
P51: J66.P$1, J66.P$2, U13.A7
P52: D84.C, R75.2, U17.A24
P53: D88.C, R79.2, U17.A34
P54: S9.2, U17.A36, U17.A37, U17.A38, U17.A39
P55: D86.C, R77.2, U17.A28, U17.A29, U17.A30, U17.A31
P56: D83.C, R74.2, U17.A27
P57: D77.4, U20.13
P58: D87.C, R78.2, U17.A19, U17.A20, U17.A21, U17.A22
P59: J79.P$1, J79.P$2, U17.A18
P60: J80.P$1, J80.P$2, U17.A17
P61: J81.P$1, J81.P$2, U17.A16
P62: D82.C, R73.2, U17.A15
P63: J83.P$1, J83.P$2, U17.A8
P64: J84.P$1, J84.P$2, U17.A7
P65: D103.C, R93.2, U21.A24
P66: D107.C, R97.2, U21.A34
P67: S11.2, U21.A36, U21.A37, U21.A38, U21.A39
P68: D105.C, R95.2, U21.A28, U21.A29, U21.A30, U21.A31
P69: D102.C, R92.2, U21.A27
P70: D96.4, U24.13
P71: D106.C, R96.2, U21.A19, U21.A20, U21.A21, U21.A22
P72: J97.P$1, J97.P$2, U21.A18
P73: J98.P$1, J98.P$2, U21.A17
P74: J99.P$1, J99.P$2, U21.A16
P75: D101.C, R91.2, U21.A15
P76: J101.P$1, J101.P$2, U21.A8
P77: J102.P$1, J102.P$2, U21.A7
PD: D12.C, R11.2, S3.1
PD1: D28.C, R18.2, S2.1
PD2: D47.C, R40.2, S5.1
PD3: D66.C, R58.2, S7.1
PD4: D85.C, R76.2, S9.1
PD5: D104.C, R94.2, S11.1
VIN: C10.1, C13.1, C14.1, D6.C, D7.A, D14.C, D16.C, R2.1, U1.P$12
VIN1: C25.1, C26.1, C27.1, D32.C, D33.A, D36.C, D37.C, R27.1, U6.P$12
VIN2: C40.1, C41.1, C42.1, D51.C, D52.A, D55.C, D56.C, R45.1, U10.P$12
VIN3: C55.1, C56.1, C57.1, D70.C, D71.A, D74.C, D75.C, R63.1, U14.P$12
VIN4: C70.1, C71.1, C72.1, D89.C, D90.A, D93.C, D94.C, R81.1, U18.P$12
VIN5: C85.1, C86.1, C87.1, D108.C, D109.A, D112.C, D113.C, R99.1, U22.P$12
VIN_TAB: D6.A, J3.P$1, J3.P$2
VIN_TAB1: D32.A, J33.P$1, J33.P$2
VIN_TAB2: D51.A, J51.P$1, J51.P$2
VIN_TAB3: D70.A, J69.P$1, J69.P$2
VIN_TAB4: D89.A, J87.P$1, J87.P$2
VIN_TAB5: D108.A, J105.P$1, J105.P$2
VOUT3.1: D34.A, J5.P$1, J5.P$2, S4.3
VOUT3.2: D53.A, J37.P$1, J37.P$2, S6.3
VOUT3.3: D9.A, J6.P$1, J6.P$2, S1.3
VOUT3.4: D72.A, J55.P$1, J55.P$2, S8.3
VOUT3.5: D91.A, J73.P$1, J73.P$2, S10.3
VOUT3.6: D110.A, J91.P$1, J91.P$2, S12.3
VOUT5.0: D11.A, J1.P$1, J1.P$2, S1.6
VOUT5.1: D35.A, J35.P$1, J35.P$2, S4.6
VOUT5.2: D54.A, J53.P$1, J53.P$2, S6.6
VOUT5.3: D73.A, J71.P$1, J71.P$2, S8.6
VOUT5.4: D92.A, J89.P$1, J89.P$2, S10.6
VOUT5.5: D111.A, J107.P$1, J107.P$2, S12.6
V_BATT: D14.A, J19.PWR
V_BATT1: D36.A, J36.PWR
V_BATT2: D55.A, J54.PWR
V_BATT3: D74.A, J72.PWR
V_BATT4: D93.A, J90.PWR
V_BATT5: D112.A, J108.PWR

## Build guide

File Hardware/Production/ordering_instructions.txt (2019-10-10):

panel size, 358x154mm
PCB thickness, 1.6mm
number of layers, 2
soldermask color, Black
silkscreen color, White
oz copper, 1oz
finish, HASL lead free
stencils, none
pcs per panel, 6

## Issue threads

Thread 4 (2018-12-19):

double-check v11 (protos for v20)

lewispg228, 2018-12-19:
1) Is "Revised by: " and the reviser's name present? [NO]
comment: missing in schematic page 2

2) Is the version number correct? [YES]
comment: yep, but let's not forget to jump it to v20 when we go to reds

3) Have you verified that the BOM in Sparkle is accurate (also checking for PROD_ID, NAME, VALUE, PREFIX)? [NO]
comment: you 100 ohm resistors are not correct in sparkle

4) If this design requires special ordering or production assembly instructions, have the symbols/packages been added with notes? (PCB thickness, humidity sensitivity, etc.) [YES]
comment: yep, black gloss. nice.

AndyEngland521, 2018-12-20:
Fixed and pushed and ordered, oh my!

Closed 2018-12-20.

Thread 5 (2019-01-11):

double-check for REDS v20

lewispg228, 2019-01-11:
1) Some text schematic overlap on D18. Maybe smash it, make slightly smaller and relocate.

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

2) SCH page 2, version number still v11, needs to be v20

AndyEngland521, 2019-01-11:
Fixed and pushed

Closed 2019-01-11.

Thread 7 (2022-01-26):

Gator:log issue

schoolwidelabs, 2022-01-26:
There is a current issue that arose during a professional learning event in Longmont last month that we are having some trouble with.

We tested this with our own tutorial (https://makecode.microbit.org/#tutorial:38195-41470-62010-14629), as well as the sample program provided in the gator:log Hookup Guide (https://learn.sparkfun.com/tutorials/sparkfun-gatorlog-hookup-guide/makecode-examples) and found issues with both. The GatorLog library was loaded via the instruction on the hookup guide linked above. Testing was completed with various micro:bit V1s (retesting was completed with a V1.3B and V1.5) with the newest firmware. Of our six participants at the event, only one worked without issue.

It appears to be an issue with the 'initialize gator:log' command, which stalls the program indefinitely and prevents the gator:log from being usable. This was identified after running test code to see where the program stalled (via a simple show icon at the beginning of on start and a clear screen block that was incrementally moved through the tutorial code until it actually cleared).

If you could take a look at this and get back to us with any information it would be greatly appreciated!

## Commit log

2017-09-15 Pulling board file from personal repo
    [breakout-a-bit.brd, breakout-a-bit.sch, gator-bit.brd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]
2017-09-15 Updated Board File Silk
    [gator-bit.brd]
2017-09-18 Updating BRD and SCH files -fixed switch problem - isolate speaker and protected pin 0 line -Added silk labels to GPIO -Aesthetics on SCH
    [gator-bit.brd, gator-bit.sch]
2017-09-18 Updated SILK on BRD file
    [gator-bit.brd]
2017-09-20 Added a battery connector
    [gator-bit.brd, gator-bit.sch]
2017-09-21 Add JST battery connector
    [gator-bit.brd]
2017-09-26 Updated design
    [gator-bit.brd, gator-bit.sch]
2017-09-26 adding OSHW logo, VIN range note
    [gator-bit.brd, gator-bit.sch]
2017-09-26 updating resistor values
    [gator-bit.brd, gator-bit.sch]
2017-10-16 Updating file
    [gator-bit.brd, gator-bit.sch]
2017-10-24 Updating Design Files
    [gator-bit.brd, gator-bit.sch]
2017-10-27 updating brd file
    [gator-bit.brd]
2017-10-27 Added Inductor
    [gator-bit.brd, gator-bit.sch]
2017-10-31 Updated Brd and Sch files
    [gator-bit.brd, gator-bit.sch]
2017-11-03 added SOT223 package for 3.3V regulated output
    [gator-bit.brd, gator-bit.sch]
2017-11-03 added holes for lego compatibility
    [gator-bit.brd, gator-bit.sch]
2017-11-03 decreased size of 3.3V polygon pour
    [gator-bit.brd]
2017-11-06 Fixing traces
    [gator-bit.brd]
2017-11-06 Updated parts with SKUs
    [gator-bit.brd, gator-bit.sch]
2017-11-06 updating Buck-Boost part
    [gator-bit.brd, gator-bit.sch]
2017-11-06 Fixing ground pour
    [gator-bit.brd]
2017-11-08 Updates Per QC Review
    [gator-bit.brd, gator-bit.sch]
2017-11-08 fixing 604 Resistor Package
    [gator-bit.sch]
2017-11-08 Updating VREG 3.0V Package
    [gator-bit.brd, gator-bit.sch]
2018-01-24 -Updated protection diodes -added a power path to be powered from the micro:bit -added master switch -added status LEDs
    [gator-bit.brd, gator-bit.sch]
2018-01-26 -Added Fuse to 3.3V input on the m:b -added silk to show users the sequence of switches -added option to choose powering from m:b (USB) or from an external power supply.
    [gator-bit.brd, gator-bit.sch]
2018-01-29 v02, silk
    [gator-bit.brd, gator-bit.sch]
2018-01-29 added logos
    [gator-bit.brd, gator-bit.sch]
2018-01-30 Updating per QC Review
    [gator-bit.brd, gator-bit.sch]
2018-01-31 Updating TXB package
    [gator-bit.brd, gator-bit.sch]
2018-02-02 prop to vect text
    [gator-bit.brd]
2018-02-26 Updated TXB0104PWR package
    [gator-bit.brd, gator-bit.sch]
2018-03-21 updating Silk Logo
    [gator-bit.brd]
2018-03-23 updated version number
    [gator-bit.brd, gator-bit.sch]
2018-03-23 updated per QC review
    [gator-bit.brd]
2018-03-28 created panel v10
    [gator-bit-Panel.brd]
2018-04-26 Updating inductor package
    [gator-bit.brd, gator-bit.sch]
2018-12-19 initial commit to v20
    [gator-bit.sch]
2018-12-20 updating schematic to include revised by on second sheet
    [gator-bit.sch]
2018-12-20 Post checklist changes
    [gator-bit.GBL, gator-bit.GBO, gator-bit.GBS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]
2019-01-10 post review/checklist changes
    [gator-bit.brd]
2019-01-11 repositioning schematic text, qc double check changes
    [gator-bit.sch]
2019-01-30 updating readme
    [gator-bit.brd]
2022-04-01 Power diodes updated
    * D6, D14, D16 schottky diodes replaced with DIO-14072 which has a 280 mV forward voltage. Sparkle BOM updated as well.
    [gator-bit.brd, gator-bit.sch]

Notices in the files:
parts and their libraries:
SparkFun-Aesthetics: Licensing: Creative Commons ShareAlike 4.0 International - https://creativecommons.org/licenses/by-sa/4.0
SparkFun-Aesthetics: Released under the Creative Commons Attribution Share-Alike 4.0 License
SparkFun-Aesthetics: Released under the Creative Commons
